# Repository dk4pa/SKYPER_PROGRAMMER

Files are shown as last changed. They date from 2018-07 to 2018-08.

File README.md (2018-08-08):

# SKYPER_PROGRAMMER
Programmer PCB for Skyper Pager e.g. NEC21A

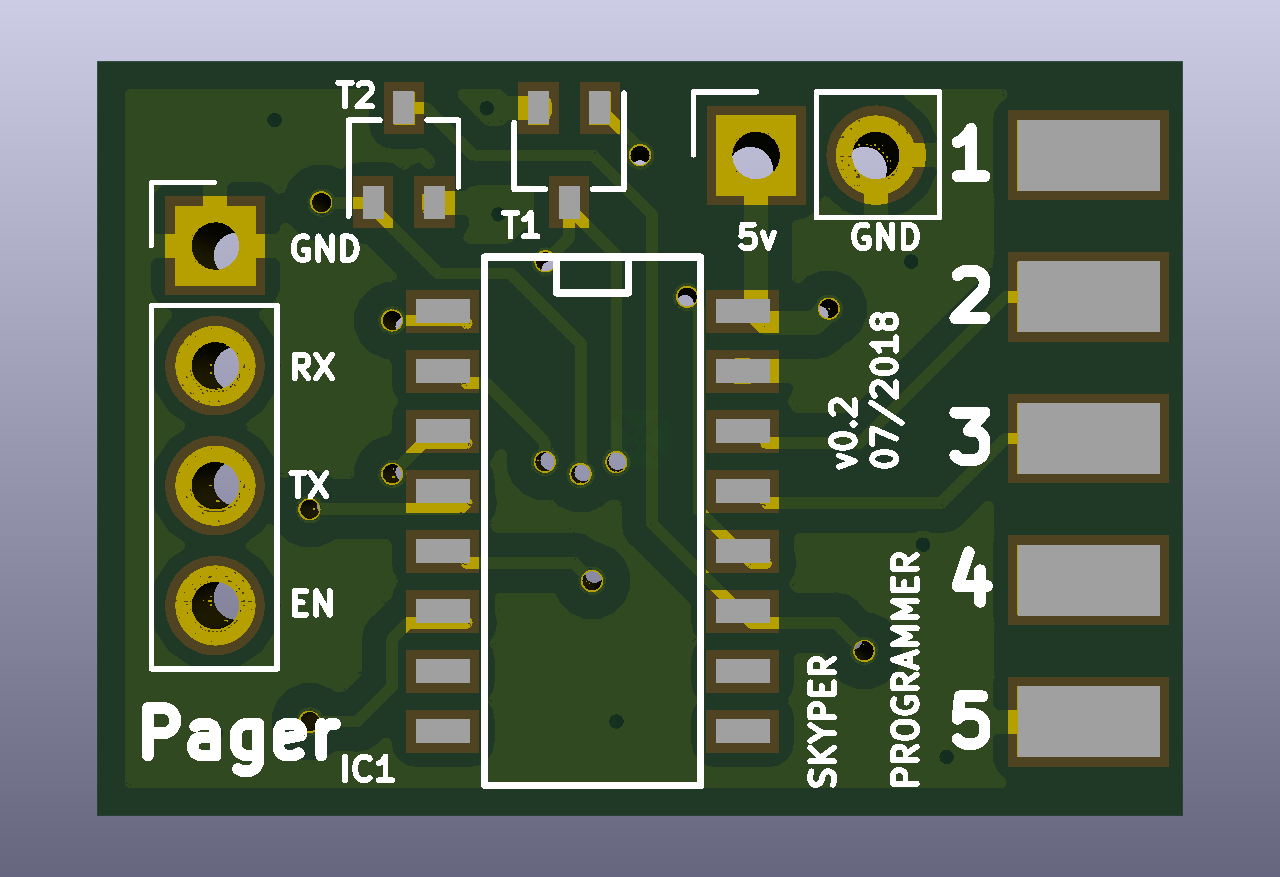
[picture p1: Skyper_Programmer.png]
PCB


# Connection to Pager

The connection to the pager is realized by 4 wires (GND, RX, TX, EN). These need to be connected as outlined in the picture.

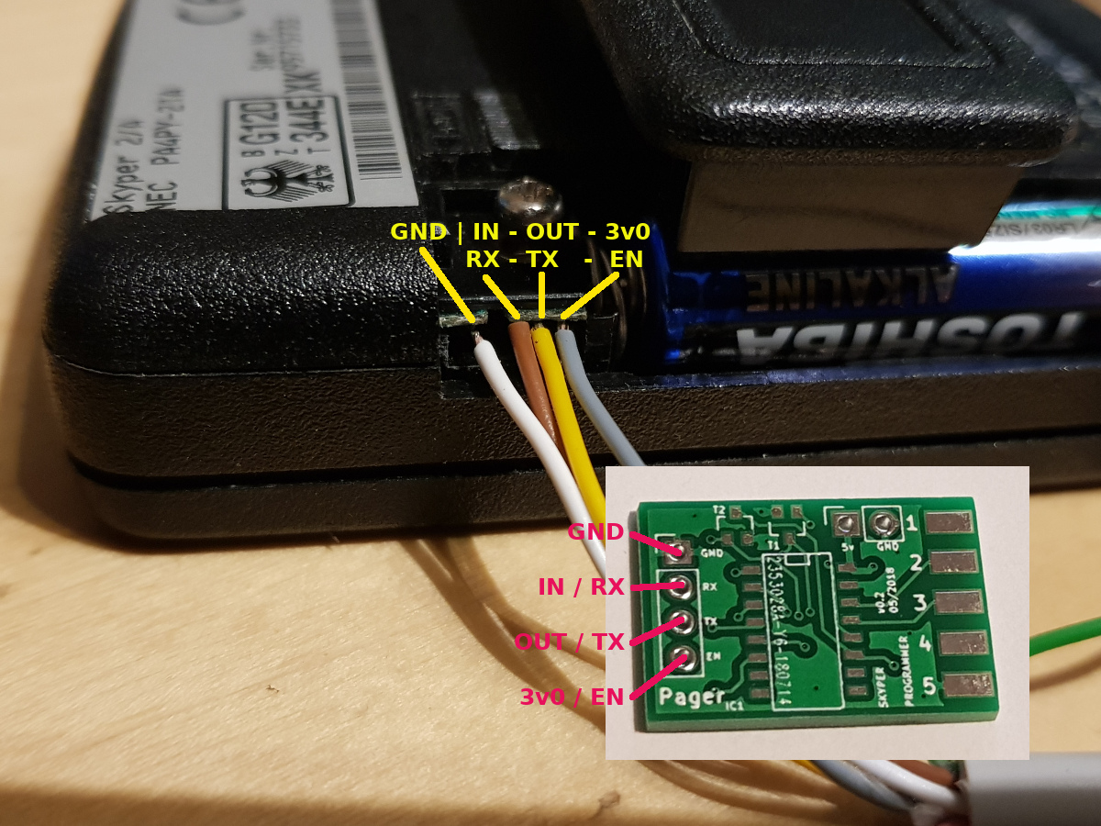
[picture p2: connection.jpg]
Connection


## Version

### v0.1

First THT version produced with Kicad 

### v0.2
SMD Version to be mounted inside a RS-232 Plug case and powered by USB cable. There is a [Mouser Cart]( https://www.mouser.com/ProjectManager/ProjectDetail.aspx?AccessID=938ca9dcb5) for the parts except the 2.54mm pins and Sub-D 9 connector.

## License

This project is released under the Creative Commons Attribution-NonCommercial-ShareAlike 3.0 (CC-BY-NC-SA 3.0, https://creativecommons.org/licenses/by-nc-sa/3.0/) license. You may edit and share it as you like, as long as credit is given and the license is not changed. You can build as many boards for you and your friends as you like and you can even sell it to them to cover your costs, however it is strictly forbidden to turn this into a commercial product! You are not allowed to build and sell these boards for profit!

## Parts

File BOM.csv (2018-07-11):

Refs | Value | Footprint | QTY | MFR | MPN | SPR | SPN
C1 | 10u | Capacitors_Tantalum_SMD:CP_Tantalum_Case-A_EIA-3216-18_Reflow | 1 | AVX | F931C106KAA | Mouser | 647-F931C106KAA
C2;C3;C5;C4 | 1u | Capacitors_Tantalum_SMD:CP_Tantalum_Case-A_EIA-3216-18_Reflow | 4 | AVX | F931C105MAA | Mouser | 647-F931C105MAA
J1 | Pager | Connector_PinHeader_2.54mm:PinHeader_1x04_P2.54mm_Vertical | 1
J2 | USB PWR | Connector_PinSocket_2.54mm:PinSocket_1x02_P2.54mm_Vertical | 1
U1 | TC1055 | Package_TO_SOT_SMD:SOT-23-5 | 1 | https://www.mouser.de/datasheet/2/268/21350c-61546.pdf | TC1055-3.0VCT713 | Mouser | 579-TC1055-3.0VCT713
R3;R1;R4 | 10k | Resistors_SMD:R_0402 | 3 | Panasonic | ERJ-PA2F1002X | Mouser | 667-ERJ-PA2F1002X
R2 | 47k | Resistors_SMD:R_0402 | 1 | Panasonic | ERJ-PA2F4702X | Mouser | 667-ERJ-PA2F4702X
IC1 | MAX232 | SMD_Packages:SO-16-N | 1 | Maxim Integrated | MAX232ESE+ | Mouser | 700-MAX232ESE
J3 | Pin1 | SubD_Connector:SubD Pad | 1
J5 | Pin2 | SubD_Connector:SubD Pad | 1
J7 | Pin3 | SubD_Connector:SubD Pad | 1
J9 | Pin4 | SubD_Connector:SubD Pad | 1
J11 | Pin5 | SubD_Connector:SubD Pad | 1
J4 | Pin6 | SubD_Connector:SubD Pad | 1
J6 | Pin7 | SubD_Connector:SubD Pad | 1
J8 | Pin8 | SubD_Connector:SubD Pad | 1
J10 | Pin9 | SubD_Connector:SubD Pad | 1
T1;T2 | BC847 | TO_SOT_Packages_SMD:SOT-323_SC-70 | 2 | ON Semiconductor | SBC847AWT1G | Mouser | 863-SBC847AWT1G

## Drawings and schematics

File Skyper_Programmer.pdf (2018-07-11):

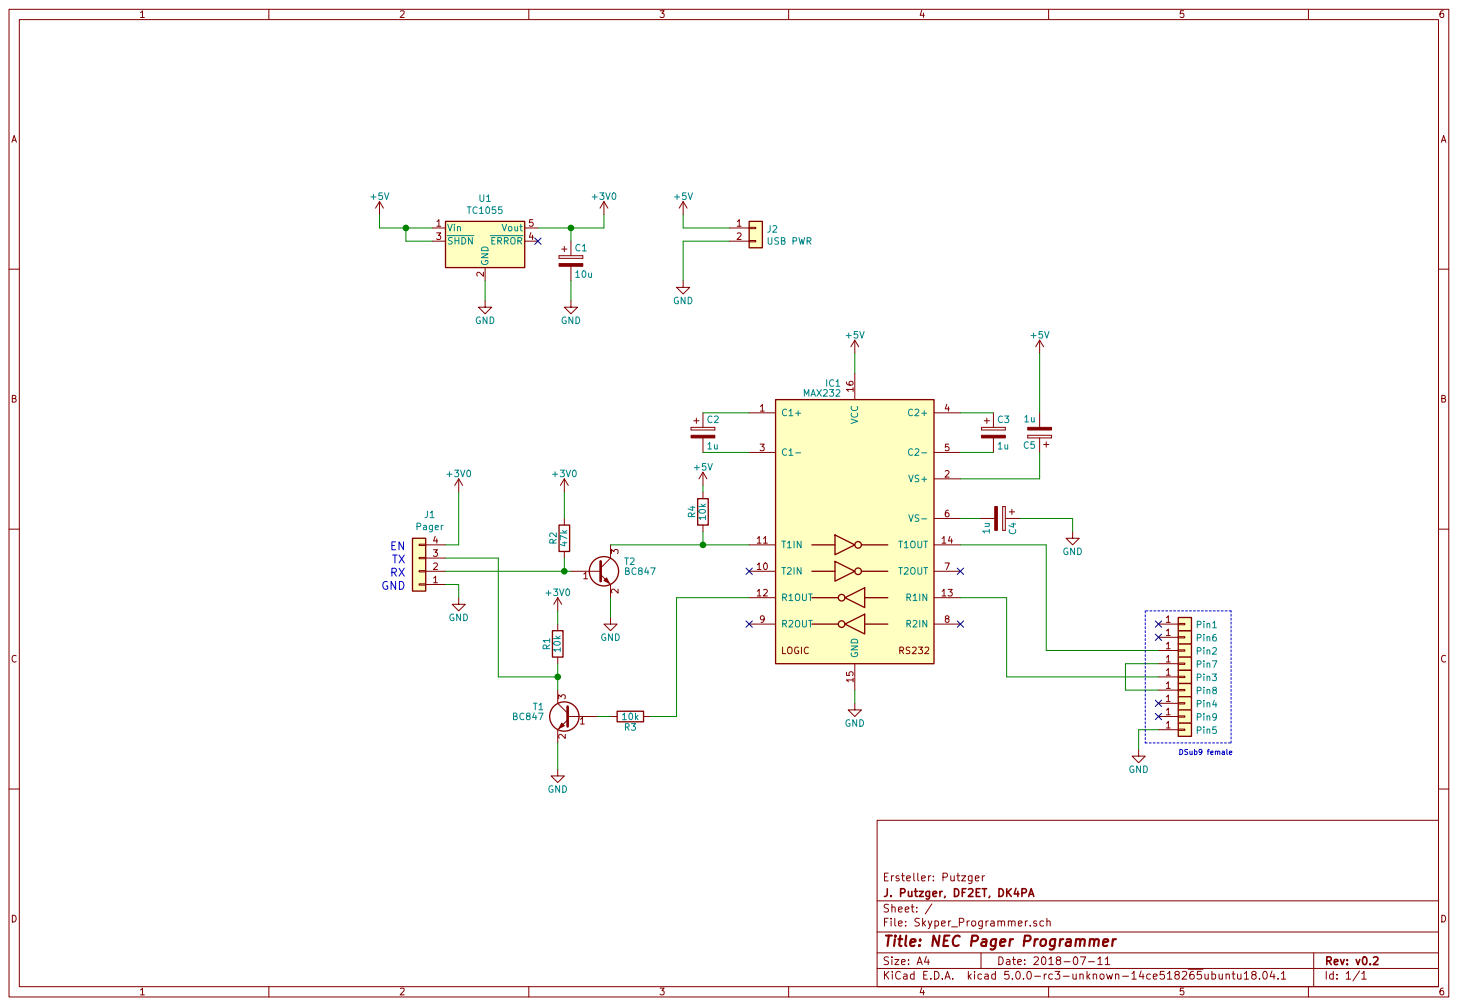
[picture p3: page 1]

File: Skyper_Programmer.sch Sheet: / J. Putzger, DF2ET, DK4PA

Id: 1/1 Title: NEC Pager Programmer

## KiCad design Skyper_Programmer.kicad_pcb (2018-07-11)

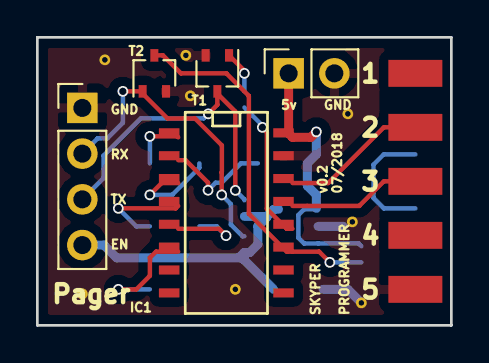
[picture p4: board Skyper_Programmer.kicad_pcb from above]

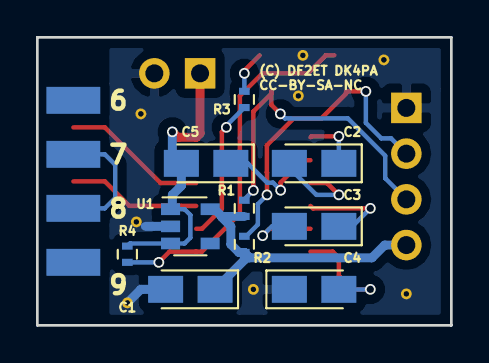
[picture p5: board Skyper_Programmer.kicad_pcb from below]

Board: 2 copper layers, 23.0 x 16.0 mm, 24 parts (14 on the bottom side), 17 nets.

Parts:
C1: 10µF; CP_Tantalum_Case-A_EIA-3216-18_Reflow
C2, C3, C4, C5: 1µF; CP_Tantalum_Case-A_EIA-3216-18_Reflow
IC1: MAX232; SO-16-N
J1: Pager; PinHeader_1x04_P2.54mm_Vertical
J2: USB PWR; PinSocket_1x02_P2.54mm_Vertical
J3: Pin1; SubD Pad
J4: Pin6; SubD Pad
J5: Pin2; SubD Pad
J6: Pin7; SubD Pad
J7: Pin3; SubD Pad
J8: Pin8; SubD Pad
J9: Pin4; SubD Pad
J10: Pin9; SubD Pad
J11: Pin5; SubD Pad
R1, R3, R4: 10k; R_0402
R2: 47k; R_0402
T1, T2: BC847; SOT-323_SC-70
U1: TC1055; SOT-23-5

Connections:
+3V0: C1.1, J1.4, R1.2, R2.2, U1.5
+5V: C5.2, IC1.16, J2.1, R4.2, U1.1, U1.3
GND: C1.2, C4.1, IC1.15, J1.1, J2.2, J11.1, T1.2, T2.2, U1.2
unnamed: C2.1, IC1.1
unnamed: C2.2, IC1.3
unnamed: C3.1, IC1.4
unnamed: C3.2, IC1.5
unnamed: C4.2, IC1.6
unnamed: C5.1, IC1.2
unnamed: IC1.11, R4.1, T2.3
unnamed: IC1.12, R3.1
unnamed: IC1.13, J7.1
unnamed: IC1.14, J5.1
unnamed: J1.2, R2.1, T2.1
unnamed: J1.3, R1.1, T1.3
unnamed: J6.1, J8.1
unnamed: R3.2, T1.1

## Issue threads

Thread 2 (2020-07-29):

Verbesserungsvorschlag

Vrumfondel, 2020-07-29:
Folgender Vorschlag - evtl. auch als Layoutoption:

Da zum einen nach meiner Erfahrung der TC1055 in Einzelstückzahlen nicht ganz einfach erhältlich ist, gleichzeitig ein MAX2323 bis runter auf 3V spezifiziert ist (in der Praxis läuft bei mir auch ein Max232 da noch problemlos) bietet es sich an als Versorgungsspannung anstelle USB/3.3V Regler einfach 2 1.5V Batterien zu verwenden.

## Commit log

2018-04-30 Update Files
    [Skyper_Programmer.kicad_pcb, Skyper_Programmer.sch]
2018-05-20 Change parts to SMD
    [Skyper_Programmer.kicad_pcb, Skyper_Programmer.sch]
2018-05-21 Add some Text to PCB
    [Skyper_Programmer.kicad_pcb]
2018-05-21 Update meta data and add PDF plot
    [Skyper_Programmer.kicad_pcb, Skyper_Programmer.sch]
2018-05-21 Add BOM data
    [Skyper_Programmer.sch]
2018-05-21 Add BOM lists
    [BOM.csv, BOM.xlsx]
2018-07-10 Change pin header labelling
    [Skyper_Programmer.kicad_pcb, Skyper_Programmer.sch]
2018-07-11 Update pic and meta data
    [Skyper_Programmer.kicad_pcb, Skyper_Programmer.sch]

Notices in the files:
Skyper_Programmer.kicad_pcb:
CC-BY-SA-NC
